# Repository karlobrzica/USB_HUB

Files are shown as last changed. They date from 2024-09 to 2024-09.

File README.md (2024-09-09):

# USB_HUB Project

## Overview

The **USB_HUB** is a custom-designed device that expands a single USB-C port into four USB-A ports. It is built using the **USB2514B-I/M2** controller, designed for **USB 2.0** communication. This USB hub is enhanced with additional features like power consumption monitoring for each of the four USB ports, displayed on a **0.96-inch IPS screen**. The device can also function as a timer, ideal for activities such as focused work sessions (e.g., a 45-minute concentration timer) or as a countdown for random tasks like boiling eggs :). Navigating through different options is done by using the knob located on the top of the case.
The hub's functionality is managed by an **STM32F103C8T6** microcontroller. 
This README outlines the hardware, software, and overall functionality of the project.

Starting_Screen
Menu_Screen
Power_Screen
Timer_Screen

## Main Components

- **USB2514B-I/M2**: This is the core USB 2.0 controller that provides a four-port USB hub.
- **STM32F103C8T6**: A microcontroller that handles display control, USB communication, and power monitoring logic.
- **0.96-inch IPS ST7789 Display**: A small display module used to show power consumption data and countdown timers. More details about this display module can be found in the [datasheet](http://www.lcdwiki.com/0.96inch_IPS_ST7789_Module).
- **INA219AIDR**: A current and power monitoring sensor responsible for measuring the power consumption of each USB port.
- **USB-C Input Port**: For connecting the device to a host device.
- **4x USB-A Output Ports**: For connecting USB devices

## Features

- **USB Hub**: Expands one USB-C port into four USB-A ports, supporting USB 2.0.
- **Power Monitoring**: Displays real-time power consumption for each of the four USB ports on the 0.96-inch screen.
- **Timer Functionality**: Can be used as a countdown timer, useful for focused work sessions or cooking tasks.
- **3D Printed Enclosure**: A custom 3D-printed enclosure with snap-fit cover design.

## Project Files

The project repository is organized into two main folders:

1. **USB_HUB_Hardware**
   - **STL Files**: 3D model files for the enclosure, including the base with M3 inserts and a snap-fit cover.
   - **Fabrication Files**: Design files for the PCB.
   - **Schematic**: The schematic showing all the components and connections.

2. **USB_HUB_Software**
   - The code uploaded to the STM32 microcontroller, written in STM32CUBEIDE.

## Enclosure Design

The enclosure for the USB hub is 3D-printed, uses M3 inserts and the top cover snaps into place.

Case
Housing
Lid

## PCB Design

This is a 4-layer PCB which is designed in EazyEDA software, schematic and fabrication files are located in USB_HUB_Hardware folder.
Lid
More details on PCB can be found [here](https://oshwlab.com/karlobrzica1997/new-project_2024-07-08_19-28-44).

## Special Thanks

A special thanks goes to **Phils_lab**, as this project is based on his original USB hub design. You can check out his informative video [here](https://www.youtube.com/watch?v=iR2hYpq0KI0&t=583s). I have added a unique twist to his design by incorporating power consumption monitoring and a countdown timer.
[Phil's Lab GitHub](https://github.com/pms67)

## Resources

- [ST7789-STM32 GitHub Floyd-Fish Repository](https://github.com/Floyd-Fish/ST7789-STM32)

## Additional Notes

Feel free to modify and expand on the project.
Use the files, hardware, and software given in this repository at your own risk

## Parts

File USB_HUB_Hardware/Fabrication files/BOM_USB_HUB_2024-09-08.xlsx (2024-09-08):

No. | Quantity | Comment | Designator | Footprint | Value | Manufacturer Part | Manufacturer | Supplier Part | Supplier
1 | 17 | 2.2uF | C1,C4,C5,C9,C10,C12,C14,C16,C18,C20,C22,C24,C26,C28,C39,C40,C45 | C0603 | 2.2uF | CL10A225KO8NNNC | SAMSUNG(三星) | C23630 | LCSC
2 | 21 | 100nF | C2,C11,C13,C17,C19,C23,C25,C29,C33,C35,C36,C37,C38,C43,C46,C47,C48,C49,C50,C51,C55 | C0402 | 100nF | CL05B104KO5NNNC | SAMSUNG(三星) | C1525 | LCSC
3 | 7 | 10uF | C3,C6,C7,C8,C15,C21,C27 | C0805 | 10uF | CL21A106KAYNNNE | SAMSUNG(三星) | C15850 | LCSC
4 | 3 | 10nF | C30,C34,C44 | C0402 | 10nF | CL05B103KB5NNNC | SAMSUNG(三星) | C15195 | LCSC
5 | 4 | 8pF | C31,C32,C41,C42 | C0402 | 8pF | GJM1555C1H8R0BB01D | muRata(村田) | C161335 | LCSC
6 | 5 | MSUSBLC6-2SC6 | D1,D2,D3,D4,D5 | SOT-23-6_L2.9-W1.6-P0.95-LS2.8-BL |  | MSUSBLC6-2SC6 | MSKSEMI(美森科) | C2830148 | LCSC
7 | 5 | BLM18SG121TN1D | L1,L2,L3,L4,L5 | L0603 |  | BLM18SG121TN1D | muRata(村田) | C113030 | LCSC
8 | 2 | KT-0603R | LED1,LED6 | LED0603-RD |  | KT-0603R | KENTO | C2286 | LCSC
9 | 4 | MHT194CRGBCT | LED2,LED3,LED4,LED5 | LED-ARRAY-SMD_0603-4P-L1.6-W1.6-BL-RD |  | MHT194CRGBCT | MEIHUA(美华) | C404275 | LCSC
10 | 4 | 100mΩ | R1,R4,R7,R9 | R1206 | 100mΩ | FBF06FT-R100-00L | PSA(信昌电陶) | C382268 | LCSC
11 | 4 | 39kΩ | R2,R6,R8,R10 | R0603 | 39kΩ | 0603WAF3902T5E | UNI-ROYAL(厚声) | C23153 | LCSC
12 | 6 | 330Ω | R3,R31,R32,R33,R34,R37 | R0402 | 330Ω | 0402WGF3300TCE | UNI-ROYAL(厚声) | C25104 | LCSC
13 | 5 | 0Ω | R5,R27,R28,R29,R30 | R0603 | 0Ω | 0603WAF0000T5E | UNI-ROYAL(厚声) | C21189 | LCSC
14 | 4 | 12kΩ | R11,R16,R25,R26 | R0402 | 12kΩ | 0402WGF1202TCE | UNI-ROYAL(厚声) | C25752 | LCSC
15 | 2 | 4.7kΩ | R12,R13 | R0402 | 4.7kΩ | 0402WGF4701TCE | UNI-ROYAL(厚声) | C25900 | LCSC
16 | 6 | 100kΩ | R19,R20,R21,R22,R23,R24 | R0402 | 100kΩ | 0402WGF1003TCE | UNI-ROYAL(厚声) | C25741 | LCSC
17 | 2 | 5.1kΩ | R35,R36 | R0402 | 5.1kΩ | 0402WGF5101TCE | UNI-ROYAL(厚声) | C25905 | LCSC
18 | 1 | MK-12C03-G015 | SW1 | SW-SMD_MK-12C03-G015 |  | MK-12C03-G015 | G-Switch(品赞) | C2890358 | LCSC
19 | 1 | B3U-1000P | SW2 | KEY-SMD_B3U-1000PM |  | B3U-1000P | OMRON(欧姆龙) | C231329 | LCSC
20 | 1 | EC11E1534408 | SW3 | SW-TH_EC11XXXXXXXX |  | EC11E1534408 | ALPSALPINE(阿尔卑斯阿尔派) | C278348 | LCSC
21 | 4 | TPS2553DBVR | U1,U5,U7,U9 | SOT-23-6_L2.9-W1.6-P0.95-LS2.8-BR |  | TPS2553DBVR | TI(德州仪器) | C55266 | LCSC
22 | 1 | TYPE-C-31-M-12 | U2 | USB-C_SMD-TYPE-C-31-M-12 |  | TYPE-C-31-M-12 | 韩国韩荣 | C165948 | LCSC
23 | 1 | AZ1117H-3.3TRG1 | U3 | SOT-223-3_L6.5-W3.4-P2.30-LS7.0-BR |  | AZ1117H-3.3TRG1 | DIODES(美台) | C110474 | LCSC
24 | 4 | INA219AIDR | U4,U6,U8,U10 | SOIC-8_L4.9-W3.9-P1.27-LS6.0-BL |  | INA219AIDR | TI(德州仪器) | C138706 | LCSC
25 | 1 | STM32F103C8T6 | U11 | LQFP-48_L7.0-W7.0-P0.50-LS9.0-BL |  | STM32F103C8T6 | ST(意法半导体) | C8734 | LCSC
26 | 1 | USB2514B-I/M2 | U12 | SQFN-36_L6.0-W6.0-P0.50-BL-EP |  | USB2514B-I/M2 | MICROCHIP(美国微芯) | C220679 | LCSC
27 | 4 | KH-AF180WJ-15-JB | USB1,USB2,USB3,USB4 | USB-A-TH_KH-AF180WJ-15-JB |  | KH-AF180WJ-15-JB | kinghelm(金航标) | C2833349 | LCSC
28 | 1 | 16MHz | X1 | CRYSTAL-SMD_4P-L2.5-W2.0-BL-A | 16MHz | NX2520SA-16MHZ-STD-CSW-5 | NDK | C280836 | LCSC
29 | 1 | 24MHz | X2 | CRYSTAL-SMD_4P-L2.0-W1.6-BL-1 | 24MHz | 7D024000F01 | HD(浩都频率) | C648932 | LCSC

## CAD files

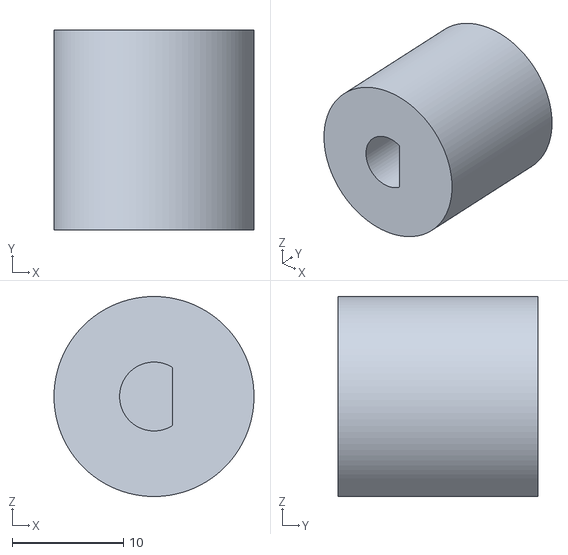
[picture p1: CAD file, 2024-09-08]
USB_HUB_Hardware/STL_Models/USB_KNOB v4.stl
18.0 x 18.0 x 18.0

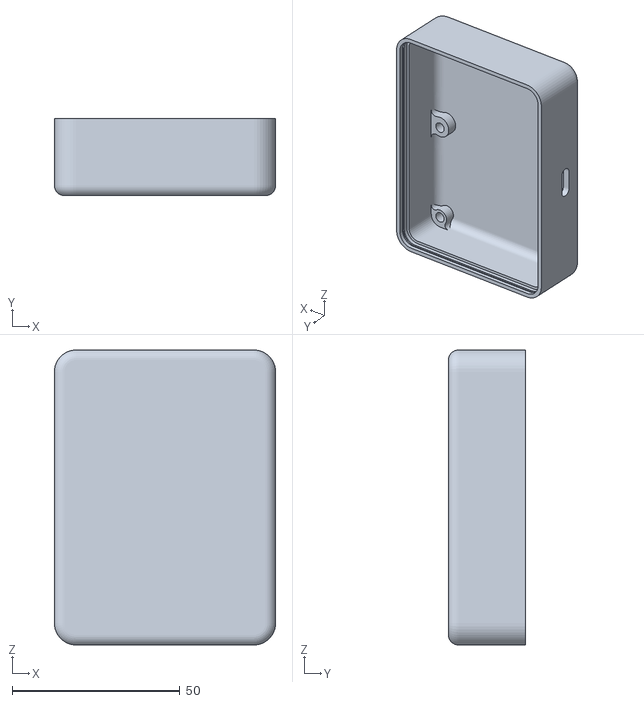
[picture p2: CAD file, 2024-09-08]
USB_HUB_Hardware/STL_Models/USB_HOUSING v7.stl
66.0 x 23.0 x 88.0

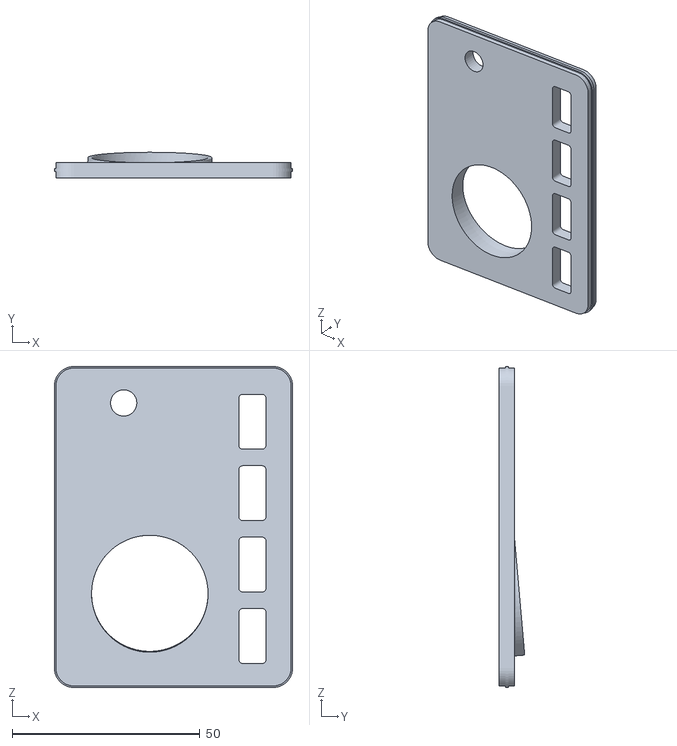
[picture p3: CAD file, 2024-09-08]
USB_HUB_Hardware/STL_Models/USB_LID v7.stl
63.4 x 6.79 x 85.4

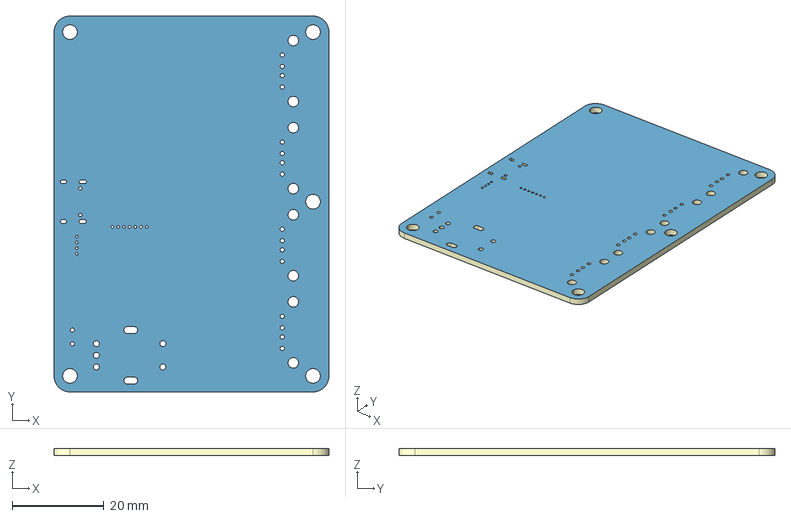
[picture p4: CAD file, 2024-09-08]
USB_HUB_Hardware/STL_Models/USB_HUB_PCB_STEP.step
60.0 x 82.0 x 1.59 mm
TopTrack
BottomTrack
Board

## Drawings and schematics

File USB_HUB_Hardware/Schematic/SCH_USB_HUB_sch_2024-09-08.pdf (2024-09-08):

# +5V to +3V3 Power

# Input USB

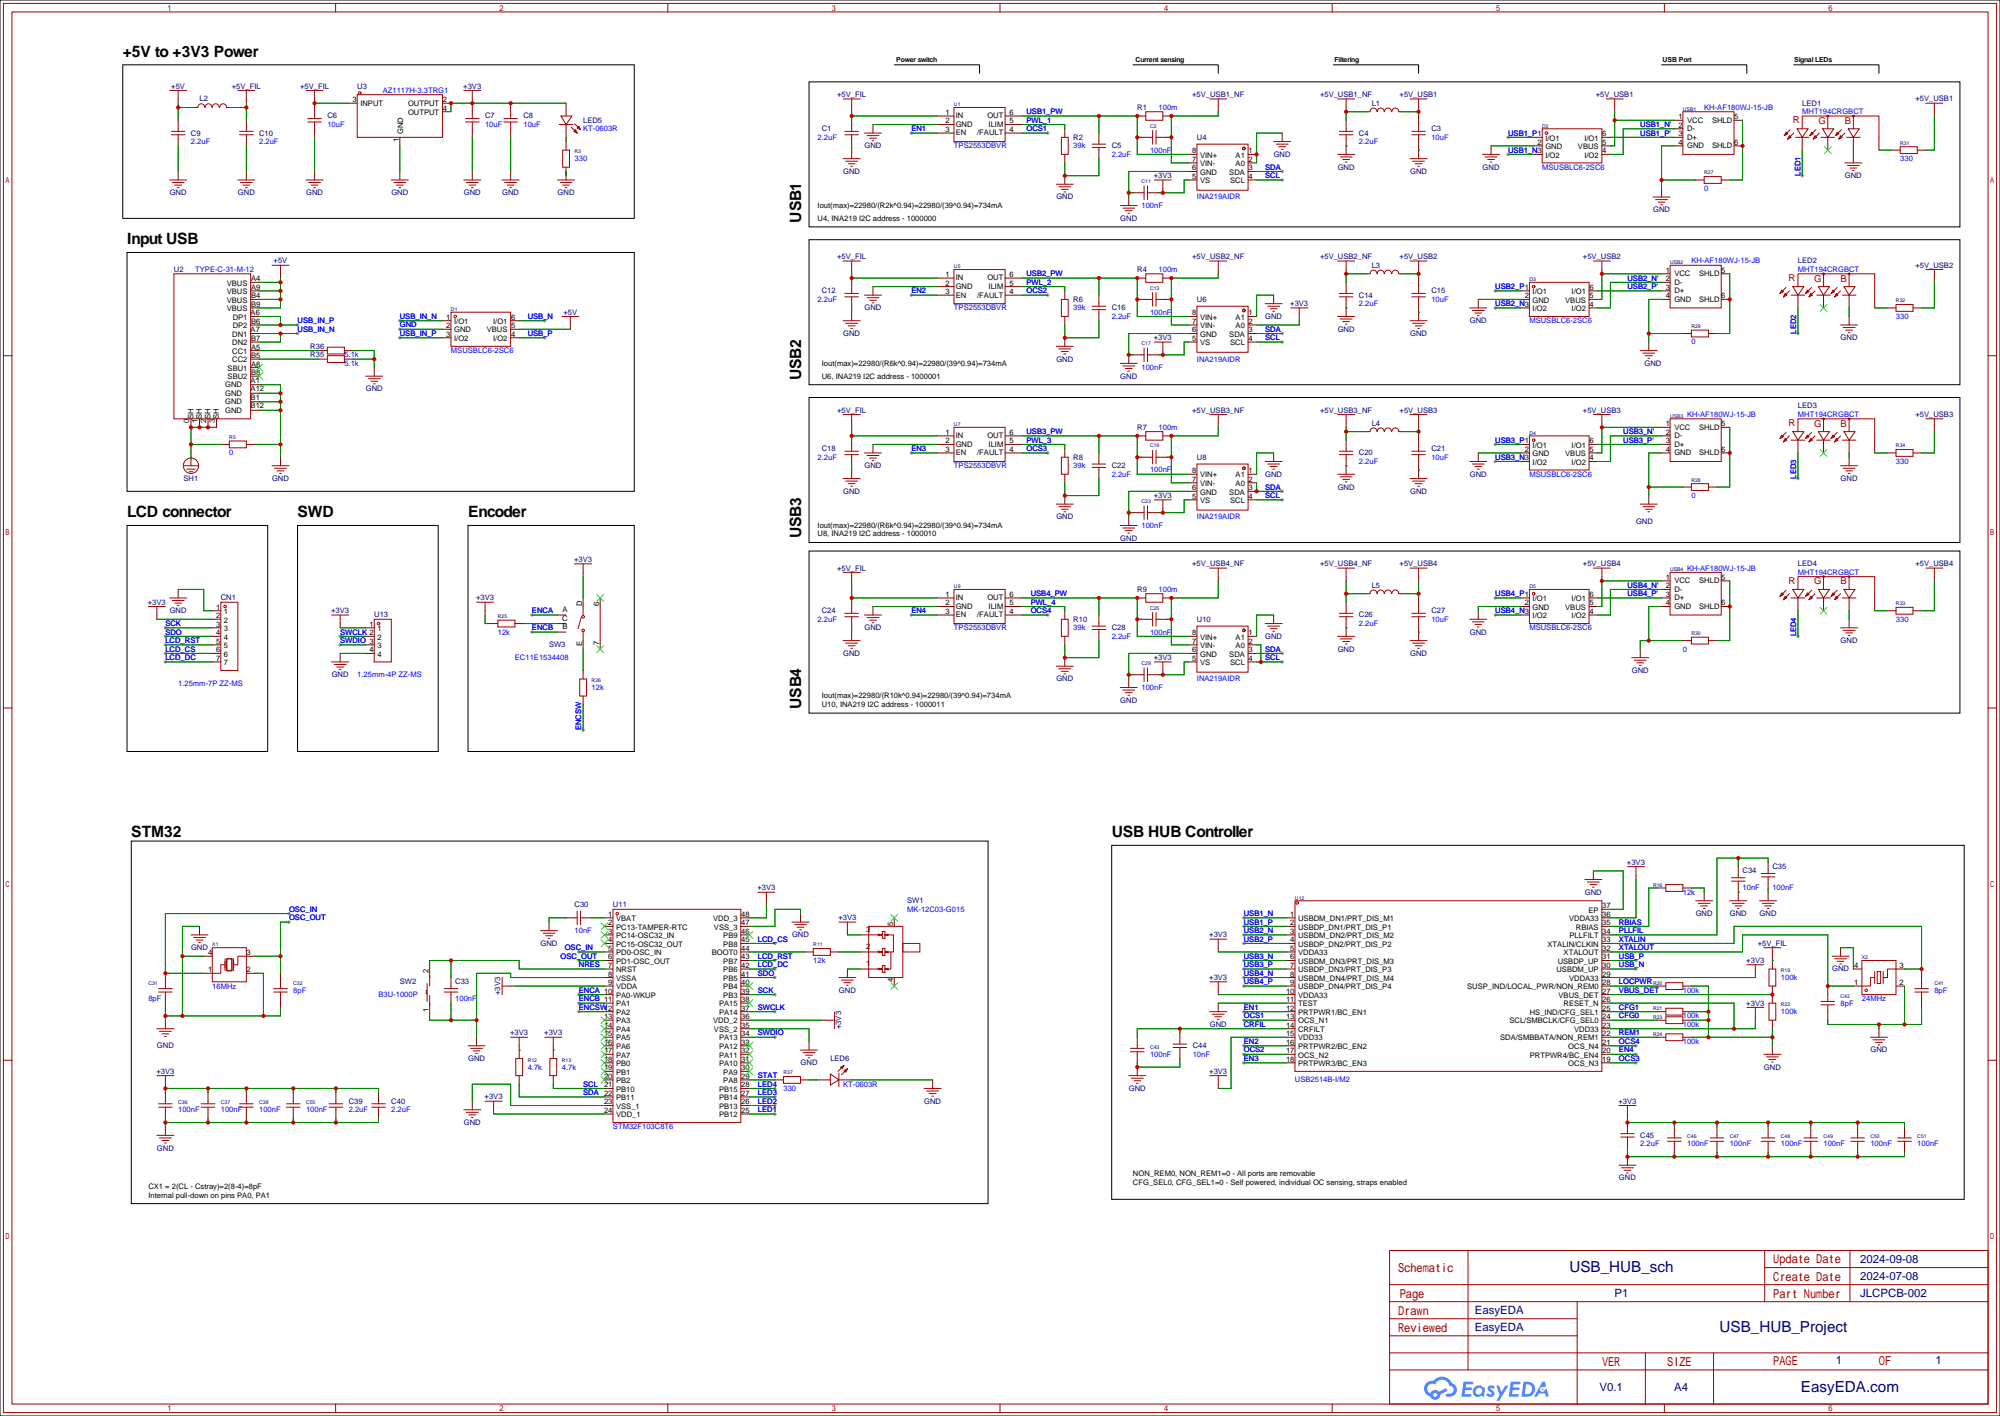
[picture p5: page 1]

NON_REM0, NON_REM1=0 - All ports are removable
CFG_SEL0, CFG_SEL1=0 - Self powered, individual OC sensing, straps enabled

CX1 = 2(CL - Cstray)=2(8-4)=8pF
Internal pull-down on pins PA0, PA1

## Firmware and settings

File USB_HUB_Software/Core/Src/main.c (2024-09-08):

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
/* Includes ------------------------------------------------------------------*/
#include "main.h"
#include "dma.h"
#include "i2c.h"
#include "spi.h"
#include "tim.h"
#include "gpio.h"

/* USER CODE BEGIN Includes */
#include "st7789.h"
#include "ina219.h"
#include "stm32f1xx_it.h"
#include <stdio.h>
#include <math.h>
/* USER CODE END Includes */


/* USER CODE BEGIN PV */

int16_t counter = 0;
uint16_t step = 0;
uint8_t selection_flag = 0;
uint8_t power_flag = 0;
uint8_t timer_flag = 0;

float bus_voltage;
float current;
float power;
char time[16];
char time_str[16];
char voltage_str[16];
char current_str[16];
char power_str[16];

/* USER CODE END PV */

void SystemClock_Config(void);
/**
  * @brief  The application entry point.
  * @retval int
  */
int main(void)
{

  /* MCU Configuration--------------------------------------------------------*/

  /* Reset of all peripherals, Initializes the Flash interface and the Systick. */
  HAL_Init();

  /* Configure the system clock */
  SystemClock_Config();

  /* Initialize all configured peripherals */
  MX_GPIO_Init();
  MX_DMA_Init();
  MX_SPI1_Init();
  MX_TIM2_Init();
  MX_I2C2_Init();
  /* USER CODE BEGIN 2 */
  ST7789_Init();    // Initialize the ST7789 display
  INA219_Init();    // Initialize the INA219 power sensor
  HAL_TIM_Encoder_Start_IT(&htim2, TIM_CHANNEL_ALL); // Start encoder with interrupt for TIM2
  ST7789_Starting_Screen(0, 40, GBLUE); // Display starting screen with coordinates (0, 40) and color GBLUE
  Main_Screen();    // Display the main screen
  HAL_Delay(100);   // Delay for 100 milliseconds to allow initialization to stabilize

  /* USER CODE END 2 */

  /* Infinite loop */
  /* USER CODE BEGIN WHILE */
  while (1)
  {


    /* USER CODE END WHILE */

    /* USER CODE BEGIN 3 */

  }
  /* USER CODE END 3 */
}

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
/* USER CODE BEGIN 4 */

/**
 * @brief  Starts a countdown timer and updates the display with the remaining time.
 *         The countdown continues until it reaches zero or the user presses the button.
 * @param  minute: The number of minutes to count down from.
 * @retval None
 */
void Countdown(uint8_t minute)
{
    uint16_t seconds = minute * 60; // Convert minutes to seconds

    int16_t centerX = 120; // X coordinate of the circle's center
    int16_t centerY = 120; // Y coordinate of the circle's center
    int16_t radius = 100;  // Radius of the circle along which the point will move

    // Draw static elements (optional)
    ST7789_DrawLine(10, 140, 30, 130, RED);  // Example static line
    ST7789_DrawLine(230, 140, 210, 130, RED); // Example static line

    while (seconds > 0)
    {
        // Format time into minutes and seconds
        uint8_t display_minutes = seconds / 60;
        uint8_t display_seconds = seconds % 60;

        // Display the formatted time on the screen
        sprintf(time, "%02d:%02d", display_minutes, display_seconds);
        ST7789_WriteString(80, 100, time, Font_16x26, GBLUE, BLACK);

        // Calculate the angle in radians (from 182° to 362°)
        float angle = M_PI * (182.0 + 180.0 * (float)(minute * 60 - seconds) / (minute * 60)) / 180.0;

        // Calculate the coordinates of the point on the circle
        int16_t x = centerX + (int16_t)(radius * cos(angle));
        int16_t y = centerY + (int16_t)(radius * sin(angle));

        // Draw the point at the new coordinates
        ST7789_DrawFilledCircle(x, y, 5, RED);

        // If there are less than 11 seconds remaining, toggle the LED
        if (seconds < 11)
        {
            HAL_GPIO_TogglePin(GPIOB, GPIO_PIN_12 | GPIO_PIN_13 | GPIO_PIN_14 | GPIO_PIN_15);
        }

        // Pause for one second
        HAL_Delay(980);

        // Erase the previous point (optional: draw a black point over it before drawing the new one)
        ST7789_DrawFilledCircle(x, y, 5, BLACK);

        // Decrease the number of seconds
        seconds--;

        // Check if the button is pressed to abort the countdown
        if (HAL_GPIO_ReadPin(GPIOA, GPIO_PIN_2) == GPIO_PIN_SET)
        {
            HAL_Delay(100); // Debounce delay
            Main_Screen();  // Return to the main screen
            return;         // Exit the function
        }
    }

    // Return to the main screen when the countdown finishes
    Main_Screen();
}


/**
 * @brief  Displays the timer screen allowing the user to set a countdown time.
 *         Updates the display with the current time and starts a countdown upon button press.
 * @retval None
 */
void Timer_Screen(void)
{
    timer_flag = 1;    // Set the flag for Timer Screen
    counter = 1;       // Initialize to 1 minute

    ST7789_Fill_Color(BLACK); // Clear the screen


    while (1)
    {
        // Display the current time set
    	ST7789_WriteString(50, 75, "Time:", Font_11x18, GBLUE, BLACK);
        sprintf(time_str,"%d min ", counter);
        ST7789_WriteString(80, 100, time_str, Font_16x26, GBLUE, BLACK);


        HAL_Delay(200); // Short delay for display stability

        // Check if the start button is pressed
        if (HAL_GPIO_ReadPin(GPIOA, GPIO_PIN_2) == GPIO_PIN_SET)
        {
            HAL_Delay(200); // Debounce delay
            ST7789_Fill_Color(BLACK); // Clear the screen
            sprintf(time_str,"Time: %d min ", counter);
			ST7789_WriteString(50, 170, time_str, Font_11x18, GBLUE, BLACK);// Display the choosen time
            ST7789_DrawRectangle(45,190,195,165,0xce79);
            Countdown(counter); // Start countdown with the current time
            break; // Exit loop after starting countdown
        }
    }

    timer_flag = 0; // Reset the flag after exiting Timer Screen
    Main_Screen();  // Return to the main screen
}

/**
 * @brief  Displays the power screen showing information for USB ports.
 *         Updates the display with voltage, current, and power for the selected USB port.
 * @retval None
 */
void Power_Screen(void)
{
    power_flag = 1;    // Set the flag for Power Screen
    counter = 0;       // Initialize to USB1

    ST7789_Fill_Color(BLACK); // Clear the screen


    while (1)
    {
        char port_name[10];
        uint8_t current_port = counter + 1; // USB ports from 1 to 4


        // Read values from the selected USB port
        switch (counter)
        {
            case 0:
                HAL_GPIO_WritePin(GPIOB, GPIO_PIN_15, GPIO_PIN_SET);
                HAL_GPIO_WritePin(GPIOB, GPIO_PIN_12|GPIO_PIN_13|GPIO_PIN_14, GPIO_PIN_RESET);
                bus_voltage = INA219_ReadBusVoltage(USB1);
                current = INA219_ReadCurrent(USB1);
                power = INA219_ReadPower(USB1);
                break;
            case 1:
                HAL_GPIO_WritePin(GPIOB, GPIO_PIN_14, GPIO_PIN_SET);
                HAL_GPIO_WritePin(GPIOB, GPIO_PIN_12|GPIO_PIN_13|GPIO_PIN_15, GPIO_PIN_RESET);
                bus_voltage = INA219_ReadBusVoltage(USB2);
                current = INA219_ReadCurrent(USB2);
                power = INA219_ReadPower(USB2);
                break;
            case 2:
                HAL_GPIO_WritePin(GPIOB, GPIO_PIN_13, GPIO_PIN_SET);
                HAL_GPIO_WritePin(GPIOB, GPIO_PIN_12|GPIO_PIN_15|GPIO_PIN_14, GPIO_PIN_RESET);
                bus_voltage = INA219_ReadBusVoltage(USB3);
                current = INA219_ReadCurrent(USB3);
                power = INA219_ReadPower(USB3);
                break;
            case 3:
                HAL_GPIO_WritePin(GPIOB, GPIO_PIN_12, GPIO_PIN_SET);
                HAL_GPIO_WritePin(GPIOB, GPIO_PIN_15|GPIO_PIN_13|GPIO_PIN_14, GPIO_PIN_RESET);
                bus_voltage = INA219_ReadBusVoltage(USB4);
                current = INA219_ReadCurrent(USB4);
                power = INA219_ReadPower(USB4);
                break;
            default:
                break;
        }

        // Display information on the screen
        sprintf(port_name, "USB %d", current_port);
        ST7789_WriteString(70, 20, port_name, Font_16x26, GBLUE, BLACK);

        sprintf(voltage_str, "Voltage: %.2f V ", bus_voltage);
        ST7789_WriteString(20, 60, voltage_str, Font_11x18, WHITE, BLACK);
        ST7789_DrawLine(20,85,bus_voltage*36,85,RED);
        ST7789_DrawLine(20+bus_voltage*36,85,200,85,BLACK);

        sprintf(current_str, "Current: %.2f A ", fabs(current));
        ST7789_WriteString(20, 105, current_str, Font_11x18, WHITE, BLACK);
        ST7789_DrawLine(20,130,22+current*200,130,RED);
	    ST7789_DrawLine(22+current*200,130,200,130,BLACK);

        sprintf(power_str, "Power:   %.2f W ", fabs(power));
        ST7789_WriteString(20, 150, power_str, Font_11x18, WHITE, BLACK);
        ST7789_DrawLine(20,175,22+fabs(power)*57,175,RED);
	    ST7789_DrawLine(22+power*57,175,200,175,BLACK);

        // Check if the return button is pressed
        if (HAL_GPIO_ReadPin(GPIOA, GPIO_PIN_2) == GPIO_PIN_SET)
        {
            HAL_Delay(200); // Debounce delay
            power_flag = 0;
            HAL_GPIO_WritePin(GPIOB, GPIO_PIN_12|GPIO_PIN_13|GPIO_PIN_14|GPIO_PIN_15, GPIO_PIN_SET);
            Main_Screen();
            break; // Exit loop after returning
        }
    }
}

/**
 * @brief  Handles the selection screen interface.
 *         Displays options and processes user input to navigate to the selected screen.
 * @retval None
 */
void Selection_Screen(void)
{
    selection_flag = 1;  // Set the flag for Selection Screen
    counter = 0;         // Initialize counter to 0

    while (1)
    {
        // Clear previous text and drawings

        // Display options based on 'counter' value
        if (counter == 0)
        {
            ST7789_WriteString(95, 30, "Power", Font_11x18, GBLUE, BLACK);
            ST7789_DrawCircle(64, 129, 48, GBLUE);
            ST7789_DrawCircle(174, 129, 48, BLACK);
        }
        else if (counter == 1)
        {
            ST7789_WriteString(95, 30, "Timer", Font_11x18, GBLUE, BLACK);
            ST7789_DrawCircle(64, 129, 48, BLACK);
            ST7789_DrawCircle(174, 129, 48, GBLUE);
        }

        // Check if the selection button is pressed
        if (HAL_GPIO_ReadPin(GPIOA, GPIO_PIN_2) == GPIO_PIN_SET)
        {
            HAL_Delay(200); // Debounce delay

            ST7789_Fill_Color(BLACK); // Clear the screen

            // Navigate to the selected screen
            if (counter == 0)
            {
                selection_flag = 0;
                Power_Screen();
            }
            else if (counter == 1)
            {
                selection_flag = 0;
                Timer_Screen();
            }
            break; // Exit loop after selection
        }
    }
}


/**
 * @brief  Initializes and displays the main screen and selection screen.
 * @retval None
 */
void Main_Screen(void)
{
  // Reset counter to 0
  counter = 0;

  // Display the main screen
  ST7789_Main_Screen();

  // Show the selection screen
  Selection_Screen();
}


/**
 * @brief  Handles the input capture callback for the timer.
 *         Updates the 'counter' variable based on the current timer value.
 * @param  htim: Timer handle used for input capture.
 * @retval None
 */

void HAL_TIM_IC_CaptureCallback(TIM_HandleTypeDef *htim)
{
    // Get the current value from the timer
    step = __HAL_TIM_GET_COUNTER(htim);

    // If in Power_Screen mode
    if (power_flag == 1)
    {
        // Update 'counter' within the range 0-3
        counter = step / 4 % 4;
        // Ensure 'counter' stays within valid range
        if (counter < 0) counter = 3;
        else if (counter > 3) counter = 0;
    }
    // If in Timer_Screen mode
    else if (timer_flag == 1)
    {
        // Update 'counter' within the range 1-60
    	counter = step / 4 % 60;
        // Ensure 'counter' stays within valid range
        if (counter < 1) counter = 60;
        else if (counter > 60) counter = 1;
    }
    // If in Selection_Screen mode
    else
    {
        // Toggle between two states: 0 and 1
        counter = step / 4;
        if (counter > 0)
        {
        	counter = (counter + 1) % 2;
        }
        else
        {
            counter = (counter - 1 + 2) % 2;  // +2 to keep result positive
        }
        // Ensure 'counter' stays within valid range
        if (counter < 0) counter = 1;
        else if (counter > 1) counter = 0;
    }

}

/* USER CODE END 4 */
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


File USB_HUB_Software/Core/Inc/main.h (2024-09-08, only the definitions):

#define SCK_Pin GPIO_PIN_3
#define SCK_GPIO_Port GPIOB
#define SDO_Pin GPIO_PIN_5
#define SDO_GPIO_Port GPIOB
#define LCD_DC_Pin GPIO_PIN_6
#define LCD_DC_GPIO_Port GPIOB
#define LCD_RST_Pin GPIO_PIN_7
#define LCD_RST_GPIO_Port GPIOB
#define LCD_CS_Pin GPIO_PIN_8
#define LCD_CS_GPIO_Port GPIOB

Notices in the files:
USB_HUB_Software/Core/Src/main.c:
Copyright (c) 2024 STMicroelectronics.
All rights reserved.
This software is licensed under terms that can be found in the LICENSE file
